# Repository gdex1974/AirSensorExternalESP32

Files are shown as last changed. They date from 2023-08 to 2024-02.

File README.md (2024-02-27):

# Air Quality Sensor - external unit

## Description

The Air Quality Sensor project contains two parts:
- [Internal unit](https://github.com/gdex1974/AirSensorInternalESP32) - the main unit placed inside the building
- External unit - the unit placed outside the building
This repository contains the hardware and software definitions for the external unit.
In the current state it's based on ESP32C3 module from DFRobot and communicate with the internal unit by ESP-NOW protocol.
The temperature, humdity and pressure are measured each minute. The PMx values are measured each hour.

## Hardware

- [Beetle ESP32-C3](https://wiki.dfrobot.com/SKU_DFR0868_Beetle_ESP32_C3) main microcontroller board
- [SPS30](https://botland.store/air-quality-sensors/15062-dust-air-sensor-sps30-pm10-pm25-pm4--5904422366094.html) sensor for particles matter measurement
- [BME280](https://botland.store/pressure-sensors/11803-bme280-humidity-temperature-and-pressure-5904422366179.html) sensor for temperature, humidity and pressure measurement
- [Pololu Mini MOSFET Switch](https://www.pololu.com/product/2810) low voltage module switch
- [Pololu U1V10F5](https://www.pololu.com/product/2564) 5V step-up module
- [Module with microUSB socket](https://botland.store/protoboard-connector-board-accessories/7668-module-with-microusb-socket-5904422300678.html) 5V power module
- [Li-Pol Akyga 1950mAh 1S 3,7V](https://www.akyga.com/products/344-lithium-polymer-battery-3-7v-1950mah-pcm-wires-l-150mm.html) Li-Pol accumulator
- [Prototype board](https://botland.store/circuit-boards/2715-universal-double-sided-board-30x70mm-5904422303280.html) used to fit most of the components

Alternalively, the ESP32-based compact boards like Lolin32-Lite could be used, the possible parts and schematics are described [here](docs/Lolin32-lite/Schematics.md)
## Software

- [esp-idf](https://github.com/espressif/esp-idf/releases/tag/v4.4.5) main framework
- [general-support-library](https://github.com/gdex1974/embedded-general-support-library) common embedded library
- [SimpleDrivers](https://github.com/gdex1974/embedded-simple-drivers) simple embedded drivers for SPS30 and BME280 sensors

## Setup

The microcontroller, switch, step-up converter and BME-280 sensor are placed on the prototype board.
It has to be cut to fit the size of the external cover. The SPS30 sensor and micro-USB socket module are placed aside and connected to the main board by the wires.
The frame and cover parts are 3D printed.

### Connection schema:

[Beetle C3 based schema](docs/BeetleC3/Schematics.md)

[Lolin32-lite based schema](docs/Lolin32-lite/Schematics.md)

## Firmware

The firmware is based on ESP-IDF framework (tested version is 4.4.6) and is written in C++17 language. The main task is to read the data from sensors and send them to the internal unit via Esp-Now protocol. The firmware is divided into several modules:

- components - contains the code of the external unit
  - general-support library - contains the code for general support functions, obtained from this repository.
  - SimpleDrivers - contains the code for the SPS30 and BME280 drivers, obtained from this repository.
- main - contains the main code of the external unit's firmware
  - AppConfig - contains the code for the application's configuration
  - AppMain - contains the app_main() function and hosts the controller object.
  - EspNowTransport - contains the code for the communication with the main unit based on Esp-Now protocol
  - DustMonitorController - contains the code for the controller class handling the main logic of the firmware
  - PTHProvider - contains the code for the class providing the data from BME280 sensor
  - SPS30DataProvider - contains the code for the class providing the data from SPS30 sensor
- CMakeLists.txt - main CMake file for the firmware
- sdkconfig - default configuration file for the ESP-IDF framework.

## Build

The main CMakeLists.txt file could be opened directly in IDE.
To build manually, do the following steps:

```shell
mkdir build
cd build
cmake -DIDF_TARGET=esp32c3 -G Ninja  ..
cd ..
idf.py build
```

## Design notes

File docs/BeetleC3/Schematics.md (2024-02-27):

## Schematics

All electronic components except SPS30 and Li-Pol are soldered to the prototype board.
To fit inside the case the board shall be cut from the top right corner to leave 9x12 soldering holes area and one mounting hole.

The Beetle C3 controller is soldered on top close to rear side. BME280 module is soldered vertically using L-shape pins at the front side.
Switch and step-up modules are soldered at the bottom. The connections are made using thin insulated wires.

- SPS30 sensor connection cable:
    - `VCC` is connected to the +5V output of the step-up converter
    - `RX`  is connected to the `IO21` on the Beetle C3
    - `TX`  is connected to the `IO20` on the Beetle C3
    - `SEL` is not connected
    - `GND` is connected to the `GND` on the switch module
- BME280 connection:
    - `SDA` is connected to the `IO1` on the Beetle C3
    - `SCL` is connected to the `IO0` on the Beetle C3
    - `GND` is connected to the `GND` on the switch module
    - `VCC` is connected to the `3V3` output on the Beetle C3
- Pololu 2810 switch connection:
    - `GND` 1 of 4 holes is connected to the GND pin of the C3 board, the others and used as the ground for the other parts
    - `On` is connected to the IO7 pin of the Beetle C3 board
    - `VIN` is connected to the Vbat of the Beetle C3 board
    - `VOUT` one hole is connected to the + input of the step-up converter. The second hole is connected to voltage divider (R1=220k, R2=330k) with the middle point's connected to the `IO4` pad of the Beetle C3.
- step-up converter connection:
    - `Vin` hole is connected to the VBAT pin of the Lolin32-lite board
    - `GND` hole is connected to the GND pin of the Lolin32-lite board
    - `Vout` hole is connected to the VCC pin of the SPS30 sensor.
- microUSB socket connection:
  - 'GND' to the 'GND' pad of the Beetle C3
  - 'VCC' to the 'Vin' pad of the Beetle C3

The stl files:

[PMSensorFrameExternalDFRobot.stl](PMSensorFrameExternalDFRobot.stl) - main frame

[PMSensorCoverExternalDFRobot.stl](PMSensorCoverExternalDFRobot.stl) - external cover

## The assembled device:

The top view on main assembly:
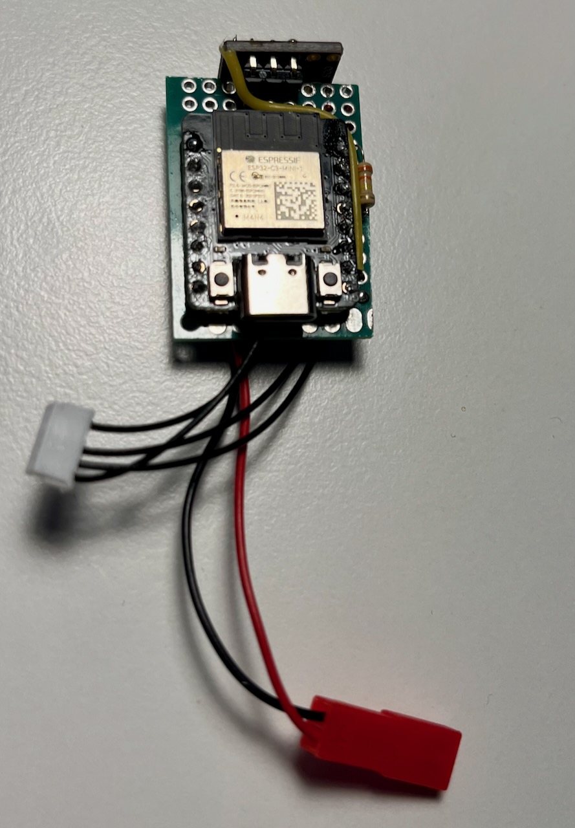
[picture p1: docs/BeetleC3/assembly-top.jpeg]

The bottom view on main assembly:
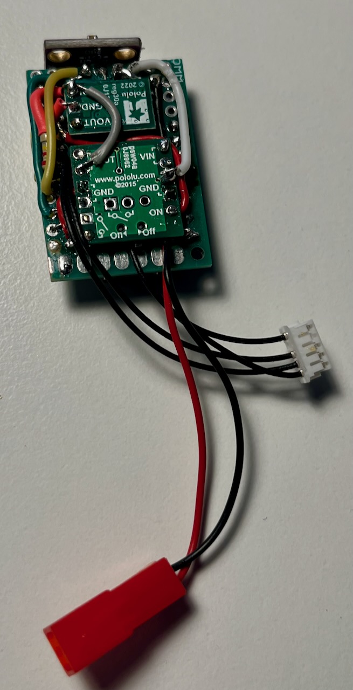
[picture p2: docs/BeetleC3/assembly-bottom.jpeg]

Pre-assembled parts
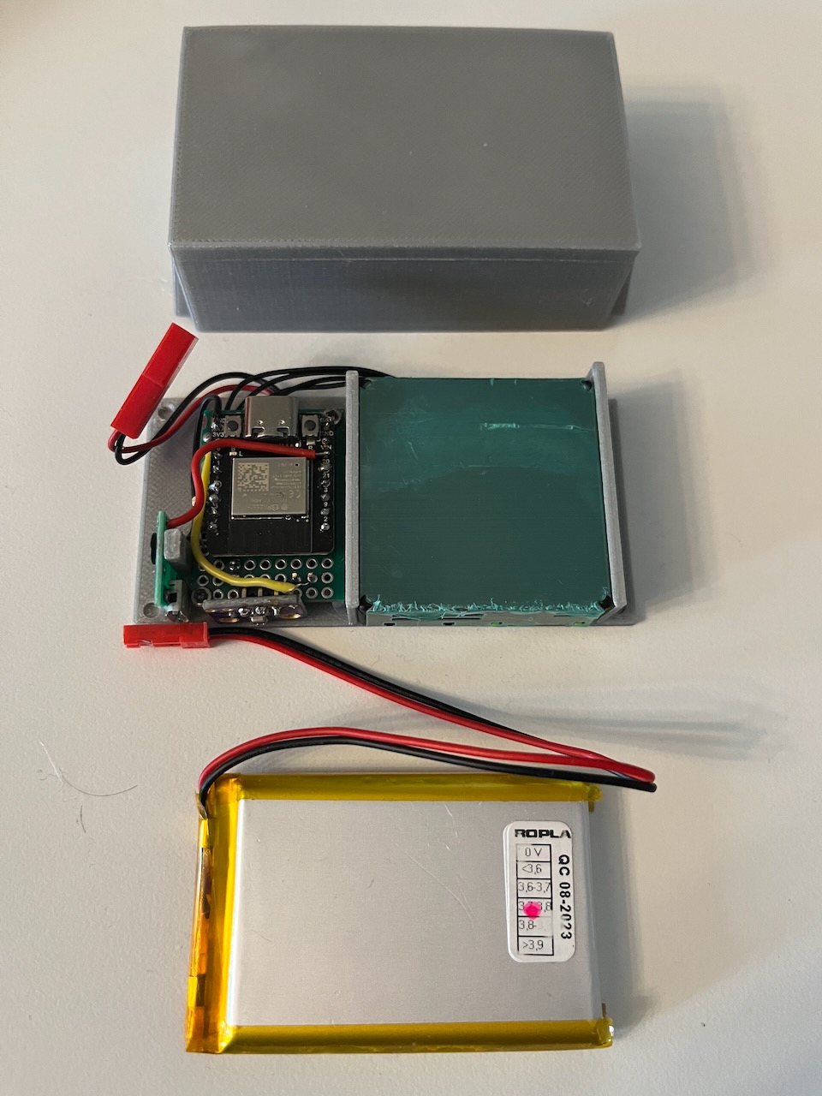
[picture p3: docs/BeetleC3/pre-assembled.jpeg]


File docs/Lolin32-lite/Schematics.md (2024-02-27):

## Schematics

- SPS30 sensor is connected to the UART2 port of the Lolin32-lite board.
    - `VCC` pin of the sensor is connected to the +5V output of the step-up converter
    - `RX` pin of the sensor is connected to the `IO27` pin of the board
    - `TX` pin of the sensor is connected to the `IO26` pin of the board
    - `SEL` pin of the sensor is not connected
    - `GND` pin of the sensor is connected to the `GND` pin of the board
- BME280 module is connected to the I2C port of the Lolin32-lite board
    - `SDA` pin of the sensor is connected to the `IO33` pin of the board
    - `SCL` pin of the sensor is connected to the `IO32` pin of the board
    - `GND` pin of the sensor is connected to the `GND` pin of the board
    - `VCC` pin of the sensor is connected to the `3V3` pin of the board
- Pololu 2810 switch is mounted _under_ the main board and handled by pass-through pins:
    - `GND` connected to the GND pin of the board
    - `Enable` pin connected to the IO12 pin of the Lolin32-lite board (next to the GND pin)
    - `VIN` pin connected to the battery+ of the Lolin32-lite board
    - `VOUT` pin connected to the + input of the step-up converter.  Addtionally, it's connected to voltage divider (R1=220k, R2=330k) and the output of the divider is connected to the `IO2` pin of the board. This pin is used to measure the battery voltage.
- step-up converter's is fixed into separated place on the frame
    - `+` input is connected to the VBAT pin of the Lolin32-lite board
    - `-` input is connected to the GND pin of the Lolin32-lite board
    - `+` output is connected to the VCC pin of the SPS30 sensor.

## Scematics

[external sensor cover](external_sensor_cover.stl)

[external sensor frame](external_sensor_frame.stl)

## The assembled device:

The side view:
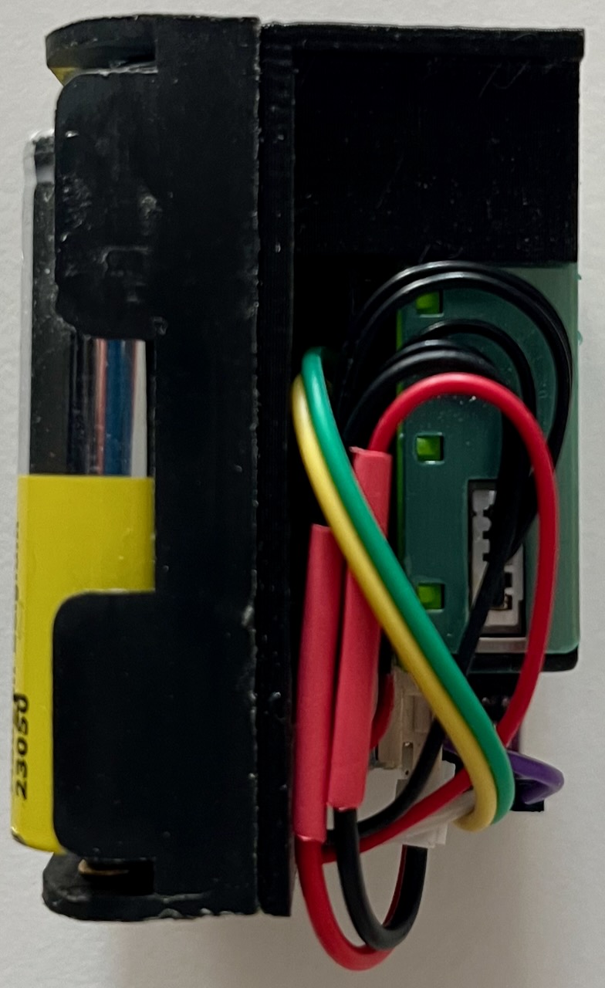
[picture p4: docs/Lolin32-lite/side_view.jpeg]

The top view:
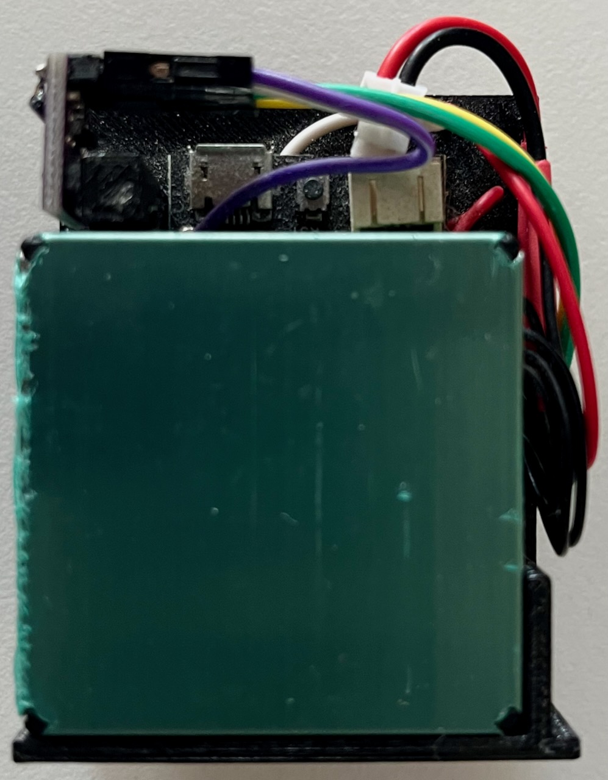
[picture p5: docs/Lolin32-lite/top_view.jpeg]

The connectors' side view:
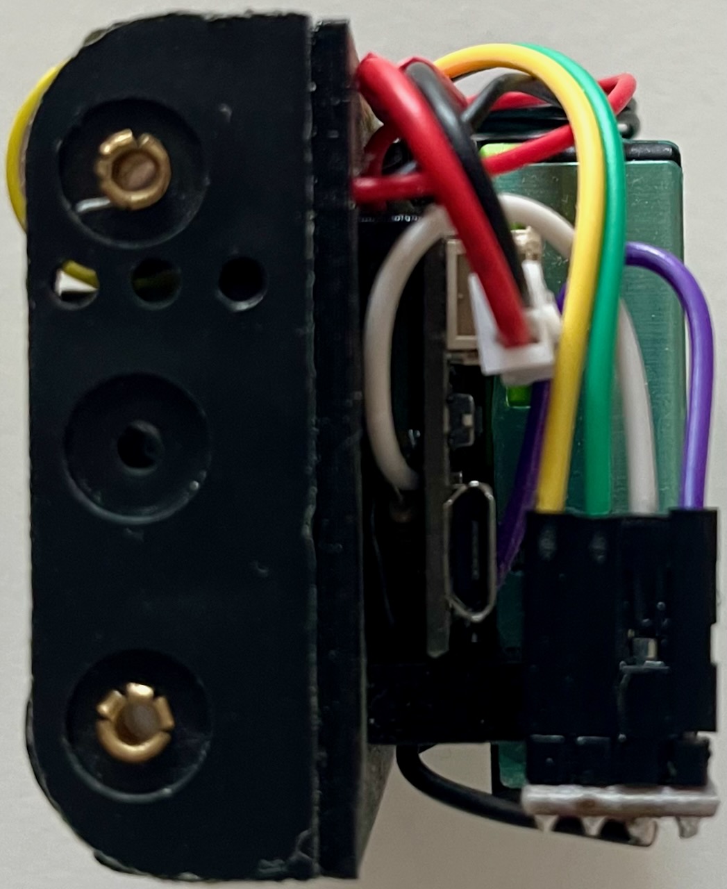
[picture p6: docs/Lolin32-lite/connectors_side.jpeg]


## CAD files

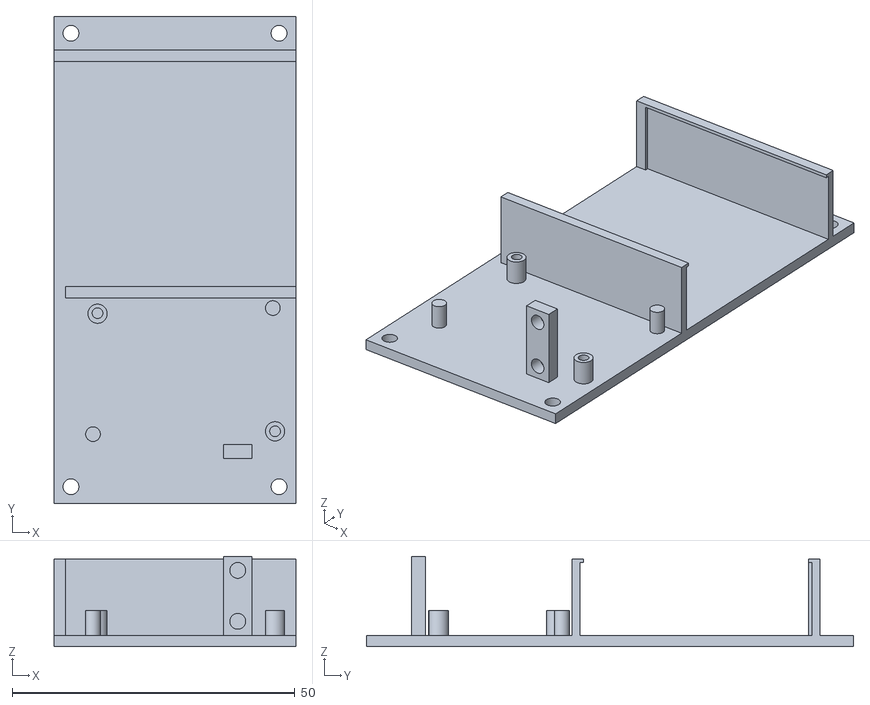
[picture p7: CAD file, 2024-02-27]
docs/BeetleC3/PMSensorFrameExternalDFRobot.stl
42.8 x 86.2 x 16.0

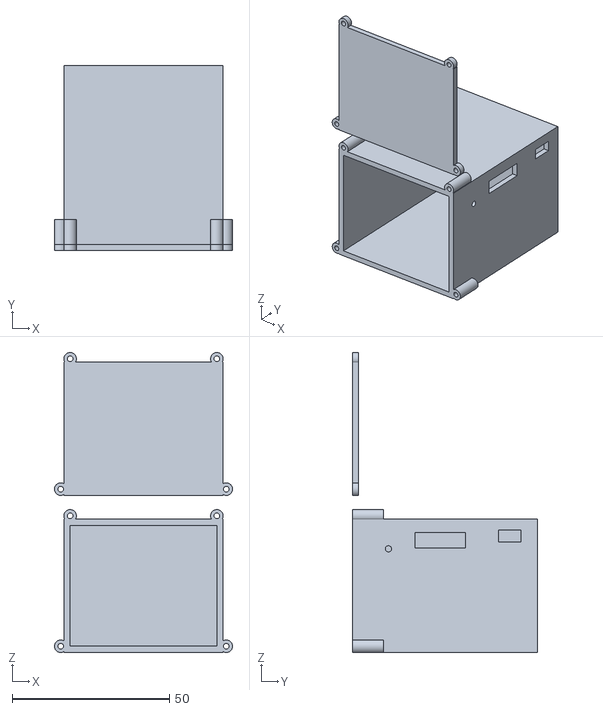
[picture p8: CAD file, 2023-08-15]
docs/Lolin32-lite/external_sensor_cover.stl
56.7 x 59.0 x 95.5

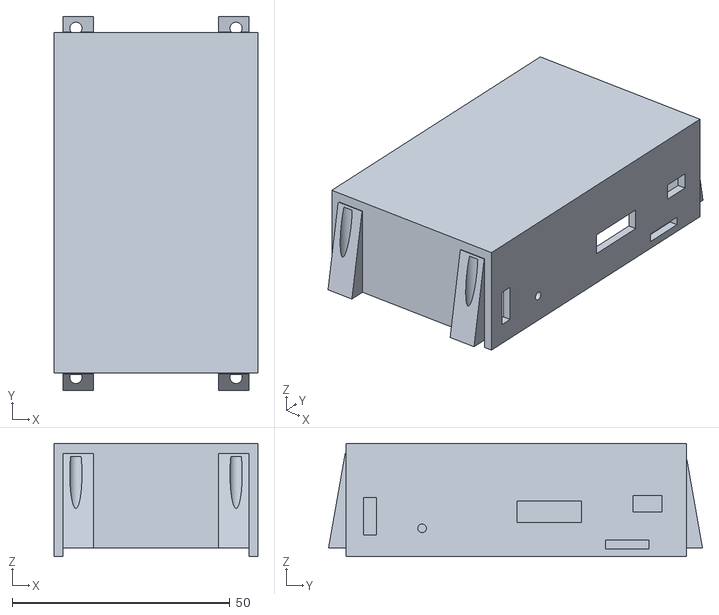
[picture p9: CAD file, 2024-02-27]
docs/BeetleC3/PMSensorCoverExternalDFRobot.stl
46.8 x 85.9 x 26.0

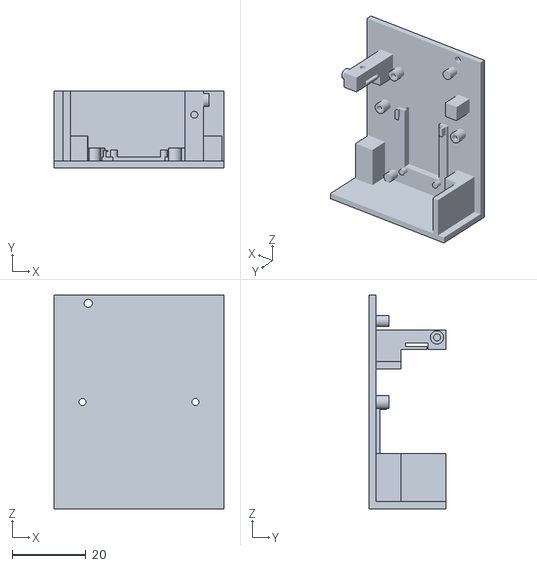
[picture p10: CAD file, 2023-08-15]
docs/Lolin32-lite/external_sensor_frame.stl
46.0 x 21.0 x 58.0

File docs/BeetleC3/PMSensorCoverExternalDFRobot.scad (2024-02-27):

$fn=180;
LiAccHeight=6.5;
LiAccWidth=40;
LiAccLength=60;
module LiIon()
{
    cube([LiAccWidth, LiAccLength, LiAccHeight]);
}

DFRobotC3Width=20.5;
DFRobotC3Length=25.0;
DFRobotC3Shift=1.5;
module DFRobotC3()
{
    height=1;
    width=DFRobotC3Width;
    length=DFRobotC3Length;
    unitWidth=13.2;
    unitLength=16.6;
    unitHeight=2.4;
    usbPlugLength=7.3;
    usbPlugWidth=9;
    cube([length, width, height]);
    translate([-DFRobotC3Shift,(width-usbPlugWidth)/2,height]) cube([usbPlugLength,usbPlugWidth,3]);
    translate([length - unitLength, (width - unitWidth)/2, height]) cube([unitLength, unitWidth, unitHeight]);
}

bmeModuleHeight=11;
module bme280spi()
{
    hole_diameter=2;
    width=15;
    height=bmeModuleHeight;
    cube([1.5, width, height]);
    translate([0, width/2, 3.6]) rotate([0, 90, 0]) cylinder(d=hole_diameter, h=5, center = false);
}

module mainUnit()
{
    boardWidth=24.4;
    boardLength=34.4;
    boardHeight=1.4;
    secondaryBoardsHeight=1.0;
    spacerHeight=2.4;
    switchLength=15.3;
    switchWidth=15.3;
    converterLength=8;
    converterWidth=13.2;
    holeShift=2.2;
    translate([0,0,spacerHeight+secondaryBoardsHeight])
    {
        cube([boardLength, boardWidth, boardHeight]);
        translate([DFRobotC3Shift, 0, boardHeight + spacerHeight]) DFRobotC3();
        translate([boardLength + 1, 2.5, -3.5]) bme280spi();
    }
    translate([4,0,0]) cube([switchLength, switchWidth, secondaryBoardsHeight]);
    translate([4 + switchLength + 2.5,0,0]) cube([converterLength, converterWidth, secondaryBoardsHeight]);
    translate([holeShift, boardWidth-holeShift, -boardHeight/2])cylinder(d=1.9, h=4.4);
    translate([33.6, 1.3, -boardHeight/2])cylinder(d=1.9, h=4.4);
}

sps30Width=41;
sps30Depth=40.8;
sps30Height=12.9;
module sps30()
{
    cube([sps30Depth,sps30Width,sps30Height]);
    bigInletWidth=6.6;
    bigInletHeight=3.8;
    translate([sps30Depth, sps30Width - bigInletWidth - 2.2, 8.2])cube([4,bigInletWidth, bigInletHeight]); // big inlet
    smallInletWidth=10;
    smallInletHeight=2;
    translate([sps30Depth, sps30Width - smallInletWidth - 5.2, -0.2])cube([4,smallInletWidth, smallInletHeight]); // small inlet
    outletWidth=14.8;
    outletHeight=5;
    translate([sps30Depth, 5.5, 5.8])cube([4,outletWidth, outletHeight]); //outlet
}

sps30CableSpace=2;
sps30CaseHeight=sps30Height+0.6;
sps30CaseWalls=2;
sps30Shift=0.6;
module sps30Case()
{
    color("black") translate([0,-sps30CaseWalls,0]) union(){
    translate([0,sps30Shift,0]) cube([sps30Depth, sps30CaseWalls, sps30CaseHeight]);
    translate([-sps30CableSpace,sps30Width+sps30CaseWalls-sps30Shift,0]) cube([sps30Depth+sps30CableSpace, sps30CaseWalls, sps30CaseHeight]);
    }
}

chargePortWidth=5;
frameBaseControlWidth=25.4;
frameBaseThickness=2;
frameBaseWidth=sps30Depth+sps30CableSpace;
frameBaseLength=frameBaseControlWidth + chargePortWidth + sps30Width + 2 * (sps30CaseWalls - sps30Shift);
baseTranslation=- frameBaseLength + sps30Width+ sps30CaseWalls - sps30Shift;
chargePortStallShift=10.3;
chargePortStallHeight=14;
chargePortHolesShift=2.5;
chargePortStallWidth=5;
sideAddition=6;
module mainFrame()
{
    difference()
    {
        sps30Case();
        sps30();
    }
    translate([0, baseTranslation, 0])
    {
        difference()
        {
           union()
           {
               translate([-sps30CableSpace, -sideAddition, - frameBaseThickness])
                    cube([frameBaseWidth, frameBaseLength+2*sideAddition, frameBaseThickness]);

               translate([3.5, chargePortWidth, 0])
               {
                   translate([2.2,22.6,0]) cylinder(d=3.4, h=4.4);
                   translate([33.6,1.8,0]) cylinder(d=3.4, h=4.4);
                   translate([1.4,1.3,0]) cylinder(d=2.6, h=4.4);
                   translate([33.2,23.6,0]) cylinder(d=2.6, h=4.4);
               }
               translate([frameBaseWidth-sps30CableSpace - chargePortStallShift - chargePortStallWidth/2,2,0]) cube([chargePortStallWidth,2.5,chargePortStallHeight]);
                translate([1, -3, -3]) cylinder(d=2.8, h=24);
                translate([frameBaseWidth - 5, -3, -3]) cylinder(d=2.8, h=24);
                translate([1, frameBaseLength + 3, -3]) cylinder(d=2.8, h=24);
                translate([frameBaseWidth - 5, frameBaseLength + 3, -3]) cylinder(d=2.8, h=24);
            }
            translate([3.5, 0.5 + chargePortWidth, 1]) mainUnit();
            translate([frameBaseWidth-sps30CableSpace-chargePortStallShift,6,chargePortHolesShift]) rotate([90,0,0]) cylinder(d=2.8, h=5);
            translate([frameBaseWidth-sps30CableSpace-chargePortStallShift,6,chargePortStallHeight - chargePortHolesShift]) rotate([90,0,0]) cylinder(d=2.8, h=5);

        }
    }
}

internalShellHeight=sps30CaseHeight + LiAccHeight + frameBaseThickness;
{
    difference()
    {
        translate([-2, -2, 0]) union() {
            cube([frameBaseWidth+4,frameBaseLength+4,internalShellHeight+4]);
            translate([2,-4,2])rotate([-10,0,0])cube([7,4,internalShellHeight]);
            translate([frameBaseWidth-5,-4,2])rotate([-10,0,0])cube([7,4,internalShellHeight]);
            translate([2,frameBaseLength+4,0])rotate([10,0,0])cube([7,4,internalShellHeight]);
            translate([frameBaseWidth-5,frameBaseLength+4,0])rotate([10,0,0])cube([7,4,internalShellHeight]);
        }
        
        translate([0,0,0])cube([frameBaseWidth,frameBaseLength,internalShellHeight]);

        translate([2, 0, 2])
        {
            translate([0, -baseTranslation,0]) 
            {
                sps30();
                mainFrame();
            }
            translate([3.5, 0.5 + chargePortWidth, 1]) mainUnit();
            translate([frameBaseWidth-sps30CableSpace - chargePortStallShift - chargePortStallWidth/2 +11,2,3]) cube([chargePortStallWidth,3,8.6]);
        }

    }
}

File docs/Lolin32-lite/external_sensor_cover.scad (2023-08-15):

$fn=180;
innerWidth=46.7;
innerHeight=38.5;
innerLength=58;
thickness=2;

module boltplace(length=10, outer=4, inner=1.8)
{
    difference() {
        cylinder(h=length, d=outer);
        cylinder(h=length, d=inner);
    }
};

union() {
    difference() {
        cube([innerWidth + 2 * thickness, innerLength+thickness-1, innerHeight + 2 * thickness]);
        translate([thickness, 0, thickness]) {
            cube([innerWidth, innerLength, innerHeight]);
            translate([innerWidth, 11.5, innerHeight-7.5]) rotate([0,90,0]) cylinder(h=10, d=2, center=true);
            translate([innerWidth, 20, innerHeight-5-2.3]) cube([10,16,5]);
            translate([innerWidth, 46.5, innerHeight-3.8-1.5]) cube([10,7.2,3.8]);
        }
    }

    translate([-1,0,2]) rotate([-90,0,0]) boltplace();
    translate([innerWidth+2*thickness+1,0,2]) rotate([-90,0,0]) boltplace();
    translate([2,0,innerHeight+5]) rotate([-90,0,0]) boltplace();
    translate([innerWidth+2*thickness-2,0,innerHeight+5]) rotate([-90,0,0]) boltplace();

}

translate([0,0,50])
union() {
    translate([-1,0,2]) rotate([-90,0,0]) boltplace(length=thickness);
    translate([innerWidth+2*thickness+1,0,2]) rotate([-90,0,0]) boltplace(length=thickness);
    translate([2,0,innerHeight+5]) rotate([-90,0,0]) boltplace(length=thickness);
    translate([innerWidth+2*thickness-2,0,innerHeight+5]) rotate([-90,0,0]) boltplace(length=thickness);
    cube([innerWidth+2*thickness, thickness, innerHeight+2*thickness]);
}

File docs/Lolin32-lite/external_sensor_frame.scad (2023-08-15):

$fn=180;
module batteryCase(size, radius)
{
height=size[2];//15;
width=size[1];//46;
length=size[0];//58;
//radius = 6;
x = width-radius;
y = height*2-radius;
z = length;
hole_diameter = 1.9;
difference() {
linear_extrude(height=z)
hull()
{
    // place 4 circles in the corners, with the given radius
    translate([(-x/2)+(radius/2), (-y/2)+(radius/2), 0])
    circle(r=radius);

    translate([(x/2)-(radius/2), (-y/2)+(radius/2), 0])
    circle(r=radius);

    translate([(-x/2)+(radius/2), (y/2)-(radius/2), 0])
    circle(r=radius);

    translate([(x/2)-(radius/2), (y/2)-(radius/2), 0])
    circle(r=radius);
}

translate([-50,0,-10])
cube([100,100,100]);
}
translate([15.3,height/2-5,length/2])rotate([90,0,0])cylinder(h=6,d=hole_diameter, center = true);
translate([-15.3,height/2-5,length/2])rotate([90,0,0])cylinder(h=6,d=hole_diameter, center = true);
}

module lolin32Lite()
{
height=7;
width=25.5;
length=50;
radius = 2;
x = length-radius;
y = width-radius;
z = height;
hole_diameter=1.9;
linear_extrude(height=z)
hull()
{
    // place 4 circles in the corners, with the given radius
    translate([(-x/2)+(radius/2), (-y/2)+(radius/2), 0])
    circle(r=radius);

    translate([(x/2)-(radius/2), (-y/2)+(radius/2), 0])
    circle(r=radius);

    translate([(-x/2)+(radius/2), (y/2)-(radius/2), 0])
    circle(r=radius);

    translate([(x/2)-(radius/2), (y/2)-(radius/2), 0])
    circle(r=radius);
}
translate([-(x/2-1), (y/2 - 1.75),height]) cylinder(d=hole_diameter, h=5, center = false);
translate([(x/2-8.5), -(y/2 -1),height]) cylinder(d=hole_diameter, h=5, center = false);
}

module bme280i2c()
{
    hole_diameter=1.9;
    cube([10.5,13.5,4]);
    translate([8, 11, 4]) cylinder(d=hole_diameter, h=5, center = false);
    translate([(10.5-8)/2, 1, 4])cube([8,2,6]);
}


module sps30()
{
    cube([41.2,41.2,12.8]);
}

module stepup5V()
{
    hole_diameter=1.9;
    union()
    {
        cube([18, 24.3, 1.5]);//3.8
        translate([2,-1,-1.5-1.4+0.6]) cube([14,21.7, 2.3+1.4-0.6]);
    }
}
difference() {
translate([-23,2,15]) rotate([90,0,0]) {
color("green"){
cube([46,58,2]);
translate([0,0,-19])cube([46,2,19]);

translate([2.4,0,-19])cube([6.8,15,19]);
translate([38.7,0,-19])cube([6.8,15,19]);

translate([4.5,38,-12])cube([4.5,5,12]);

translate([13,5.7,-1])    cube([20,24.3,1]);
translate([13+0.4,27,-2.8])    cube([1.2,3,2.5]);
translate([13+18.3,27,-2.8])    cube([1.2,3,2.5]);

translate([-9+23,-13.6,-2]) rotate([0,0,0]) union()
{
    //stepup5V();
    translate([(18-1)-1.2, 24.3-1-1.5, -1]) cylinder(d=1.9, h=3, center = false);
    translate([(0+1)+1.2, 24.3-1-1.5, -1]) cylinder(d=1.9, h=3, center = false);
}

translate([35.5,40,-19])
difference() {
union()
{
    cube([5,8.5,19]);
    translate([5,6.5,2.5])rotate([0,90,0])cylinder(d=3.6,h=3, center= true);
}
translate([-1,4,5])cube([7,1,6]);
translate([-1,2,5])cube([7,2,0.2]);
translate([2.5,6.5,6.5])rotate([90,0,0])cylinder(d=1.9,h=5, center= true);
}
translate([23+15.3,29,-1.75])cylinder(h=3.5,d=3.5, center = true);
translate([23-15.3,29,-1.75])cylinder(h=3.5,d=3.5, center = true);
translate([23-11,29-26.5+2,-1.75])cylinder(h=3.5,d=3.5, center = true);
translate([23+12,29-26.5+2,-1.75])cylinder(h=3.5,d=3, center = true);
translate([23+9.75,29+12+2,-1.75])cylinder(h=3.5,d=3.5, center = true);
translate([23-12,29+20+2,-1.75])cylinder(h=3.5,d=3, center = true);
}
}
translate([-21.75+8,1,71.75-1])rotate([90,0,0])cylinder(d=2.2, h=4, center=true);
translate([-1,12.5,40.5+2]) rotate([90,-90,0]) lolin32Lite();

translate([23,10.5,72.5])rotate([-90,0,90]) bme280i2c();

translate([0,0,15])batteryCase([58, 46, 15], 6);
translate([-18.5,21.5,17])rotate([90,0,0])sps30();

translate([-9,3,45]) rotate([-90,0,0]) difference()
{
    stepup5V();
            translate([(18-1)-1.2, 24.3-1-1.5, -2]) cylinder(d=1.9, h=4, center = false);
        translate([(0+1)+1.2, 24.3-1-1.5, -2]) cylinder(d=1.9, h=4, center = false);
}
}

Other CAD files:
docs/BeetleC3/PMSensorFrameExternalDFRobot.scad

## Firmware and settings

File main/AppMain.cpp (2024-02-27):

#include "DustMonitorController.h"

#include "AppConfig.h"

#include "Delays.h"
#include "PacketUart.h"
#include "PersistentStorage.h"

#include "esp32-esp-idf/PacketUartImpl.h"
#include "esp32-esp-idf/I2CBus.h"
#include "esp32-esp-idf/SleepFunctions.h"

#include <esp_system.h>
#include <nvs_flash.h>

#include "Debug.h"

using ResetReason = DustMonitorController::ResetReason;
namespace
{
class ControllerHolder
{
public:
    ControllerHolder(embedded::PersistentStorage& storage, int serialPortNum, int8_t address, bool restrictTxPower)
        : i2CBus(0)
        , i2CDevice(i2CBus, address)
        , uart2Device(serialPortNum)
        , uart2(uart2Device)
        , controller(storage, uart2, i2CDevice, restrictTxPower)
    {
        i2CBus.init(AppConfig::SDA, AppConfig::SCL, 100000);
    }
    DustMonitorController& getController() { return controller; }
private:
    embedded::I2CBus i2CBus;
    embedded::I2CHelper i2CDevice;
    embedded::PacketUart::UartDevice uart2Device;
    embedded::PacketUart uart2;
    DustMonitorController controller;
};

RTC_DATA_ATTR std::array<uint8_t, 2048> persistentArray;
std::optional<embedded::PersistentStorage> persistentStorage;
std::optional<ControllerHolder> controllerHolder;

ResetReason getResetReason()
{
    ResetReason resetReason;
    switch (esp_reset_reason())
    {
    case ESP_RST_DEEPSLEEP:
        resetReason = ResetReason::DeepSleep;
        break;
    case ESP_RST_BROWNOUT:
        resetReason = ResetReason::BrownOut;
        break;
    case ESP_RST_POWERON:
    default:
        resetReason = ResetReason::PowerOn;
        break;
    }
    return resetReason;
}

bool setup(ResetReason resetReason)
{
#ifdef DEBUG_SERIAL_OUT
    embedded::PacketUart::UartDevice::init(0, AppConfig::serial1RxPin, AppConfig::serial1TxPin, 115200);
#endif
    DEBUG_LOG((resetReason == ResetReason::DeepSleep ? "Wake up after sleep" : (resetReason == ResetReason::BrownOut ? "Reset after voltage drop" : "Initial startup")))
    persistentStorage.emplace(persistentArray, resetReason != ResetReason::DeepSleep);
    embedded::PacketUart::UartDevice::init(AppConfig::Sps30UartNum, AppConfig::sps30RxPin, AppConfig::sps30TxPin, 115200);
    controllerHolder.emplace(*persistentStorage, AppConfig::Sps30UartNum, AppConfig::bme280Address, AppConfig::restrictTxPower);
    return controllerHolder->getController().setup(resetReason);
}

}

extern "C" [[noreturn]] void app_main()
{
    esp_err_t ret = nvs_flash_init();
    if (ret == ESP_ERR_NVS_NO_FREE_PAGES || ret == ESP_ERR_NVS_NEW_VERSION_FOUND) {
        ESP_ERROR_CHECK( nvs_flash_erase() );
        ret = nvs_flash_init();
    }
    ESP_ERROR_CHECK( ret );
    ResetReason resetReason = getResetReason();
    if (!setup(resetReason))
    {
        DEBUG_LOG("Setup failed. No sensors found of failed to initialize WiFi. Terminating...")
        embedded::delay(1000);
        std::terminate();
    }

    const auto delayTime = controllerHolder->getController().process();
    controllerHolder->getController().hibernate();
    DEBUG_LOG("Going to deep sleep for " << delayTime << " ms")
    embedded::deepSleep(delayTime);
}

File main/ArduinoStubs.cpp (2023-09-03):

#include "DustMonitorController.h"

#include "AppConfig.h"

#include "Delays.h"
#include "PacketUart.h"
#include "PersistentStorage.h"

#include "esp32-esp-idf/PacketUartImpl.h"
#include "esp32-esp-idf/I2CBus.h"
#include "esp32-esp-idf/SleepFunctions.h"

#include <esp_system.h>
#include <nvs_flash.h>

#include "Debug.h"

namespace
{
struct DriversHolder
{
    DriversHolder(embedded::PersistentStorage& storage, int i2CBusNum, int serialPortNum, int8_t address)
        : i2CBus(i2CBusNum)
        , i2CDevice(i2CBus, address)
        , uart2Device(serialPortNum)
        , uart2(uart2Device)
        , controller(storage, uart2, i2CDevice)
    {
        i2CBus.init(AppConfig::SDA, AppConfig::SCL, 100000);
    }
    embedded::I2CBus i2CBus;
    embedded::I2CHelper i2CDevice;
    embedded::PacketUart::UartDevice uart2Device;
    embedded::PacketUart uart2;
    DustMonitorController controller;
};

RTC_DATA_ATTR std::array<uint8_t, 2048> persistentArray;
std::optional<embedded::PersistentStorage> persistentStorage;
std::optional<DriversHolder> driversHolder;

bool wakeUp = false;
}

void setup()
{
    wakeUp = esp_reset_reason() == ESP_RST_DEEPSLEEP;
    persistentStorage.emplace(persistentArray, !wakeUp);
#ifdef DEBUG_SERIAL_OUT
    embedded::PacketUart::UartDevice::init(0, AppConfig::serial1RxPin, AppConfig::serial1TxPin, 115200);
#endif
    DEBUG_LOG((wakeUp ? "Wake up after sleep" : "Initial startup"))
    embedded::PacketUart::UartDevice::init(2, AppConfig::serial2RxPin, AppConfig::serial2TxPin, 115200);
    driversHolder.emplace(*persistentStorage, 0, 2, AppConfig::bme280Address);
    if (!driversHolder->controller.setup(wakeUp)) {
        DEBUG_LOG("Setup failed!");
    }
}

void loop()
{
    auto delayTime = driversHolder->controller.process();
    if (delayTime > 700)
    {
        driversHolder->controller.hibernate();
        DEBUG_LOG("Going to deep sleep for " << delayTime << " ms")
        embedded::deepSleep(delayTime);
    }
    embedded::delay(delayTime);
}

extern "C" void app_main()
{
    esp_err_t ret = nvs_flash_init();
    if (ret == ESP_ERR_NVS_NO_FREE_PAGES || ret == ESP_ERR_NVS_NEW_VERSION_FOUND) {
        ESP_ERROR_CHECK( nvs_flash_erase() );
        ret = nvs_flash_init();
    }
    ESP_ERROR_CHECK( ret );
    setup();
    while (true)
    {
        loop();
    }
}

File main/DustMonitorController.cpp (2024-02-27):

#include "DustMonitorController.h"
#include "HardwareSensorControl.h"

#include "TimeFunctions.h"
#include "AppConfig.h"

#include <PacketUart.h>
#include <PersistentStorage.h>
#include "AnalogPin.h"

#include "esp32-esp-idf/GpioPinDefinition.h"

#include <Debug.h>

namespace
{
constexpr int sps30MeasurementDuration = 30; //seconds
constexpr int insufficientPowerThreshold = 50 * 60; //seconds

constexpr float rawToVolts = 3.3f/4095;
constexpr std::string_view controllerDataTag = "DMC";

bool isTimeSyncronized(time_t time)
{
    return time > 1692025000;
}

tm getLocalTime(time_t time)
{
    tm info {};
    localtime_r(&time, &info);
    return info;
}

int readVoltageRaw()
{
    embedded::GpioPinDefinition voltagePin { AppConfig::voltagePin };
    const auto voltage = embedded::AnalogPin(voltagePin).singleRead();
    DEBUG_LOG("VoltageRaw is " << voltage)
    return voltage;
}

void correctTime(const int64_t correction)
{
    if (std::abs(correction) > 10000)
    {
        auto nowMicroseconds = microsecondsNow();
        nowMicroseconds += correction;
        const auto nowSeconds = static_cast<decltype(timeval::tv_sec)>(nowMicroseconds / microsecondsInSecond);
        timeval correctedTimeval {
                .tv_sec = nowSeconds,
                .tv_usec = static_cast<decltype(timeval::tv_usec)>(nowMicroseconds - nowSeconds * microsecondsInSecond)
        };
        settimeofday(&correctedTimeval, nullptr);
        DEBUG_LOG("Time is corrected by " << correction << " us")
    }
    else
    {
        DEBUG_LOG("Small correction factor " << correction << " us is skipped")
    }
}

enum class SensorFlags : uint32_t {
    BatteryFailure = 1 << 0,
};
} // namespace

bool DustMonitorController::setup(ResetReason resetReason)
{
    bool wakeUp = resetReason == ResetReason::DeepSleep;
    if (!wakeUp)
    {
        HardwareSensorControl::initStepUpControl(false);
        controllerData.insufficientPower = (resetReason == ResetReason::BrownOut);
        HardwareSensorControl::activateDeepSleepGpioHold();
        HardwareSensorControl::switchStepUpConversion(true);
    }
    else
    {
        if (auto data = storage.get<ControllerData>(controllerDataTag))
        {
            controllerData = *data;
        }
        HardwareSensorControl::initStepUpControl(SPS30Status::Measuring == controllerData.sps30Status);
    }
    sensorPresent = dustData.setup(wakeUp);
    if (!wakeUp)
    {
        controllerData.voltageRaw = readVoltageRaw();
        if (sensorPresent)
        {
            const auto serial = dustData.getSpsSerial();
            memcpy(controllerData.sps30Serial, serial.begin(), serial.size());
            dustData.sleep();
            HardwareSensorControl::switchStepUpConversion(false);
        }
    }
    auto meteoResul = meteoData.setup(wakeUp);
    auto viewResult = transport.setup(controllerData.sps30Serial, wakeUp);
    return (meteoResul | sensorPresent)  && viewResult ;
}

uint32_t DustMonitorController::process()
{
    const auto currentTime = time(nullptr);
    const bool isTimeGood = isTimeSyncronized(currentTime);
    if (isTimeGood)
    {
        if (controllerData.firstSyncTime == 0)
        {
            controllerData.firstSyncTime = currentTime;
        }
        if (sensorPresent)
        {
            if (!controllerData.insufficientPower)
            {
                processSPS30Measurement();
            }
            else
            {
                HardwareSensorControl::switchStepUpConversion(false);
                if (currentTime - controllerData.firstSyncTime > insufficientPowerThreshold)
                {
                    controllerData.insufficientPower = false;
                }
            }
        }
        needSend = getLocalTime(currentTime).tm_sec == 59;
    }
    else
    {
        needSend = true;
    }

    if (needSend)
    {
        needSend = false;
        if (meteoData.activate() && meteoData.doMeasure())
        {
            meteoData.hibernate();
        }
        transport.sendData(
                { meteoData.getHumidity(), meteoData.getTemperature(), meteoData.getPressure(), controllerData.pm01
                  , controllerData.pm25, controllerData.pm10, float(controllerData.voltageRaw) * rawToVolts / AppConfig::batteryVoltageDivider
                  , (controllerData.insufficientPower ? (uint32_t)SensorFlags::BatteryFailure : 0) });
    }
    if (transport.getStatus() == EspNowTransport::SendStatus::Completed)
    {
        correctTime(transport.getCorrection());
    }

    auto nowMicroseconds = microsecondsNow();
    const int64_t wholeMinutePast = (nowMicroseconds / microsecondsInMinute) * microsecondsInMinute;
    const auto microsecondsTillNextMinute = wholeMinutePast + microsecondsInMinute - nowMicroseconds;
    uint32_t delayTime = (microsecondsTillNextMinute <= HardwareSensorControl::bootEstimationMicroseconds) ?
                        microsecondsInMinute + microsecondsTillNextMinute : microsecondsTillNextMinute;
    delayTime -= HardwareSensorControl::bootEstimationMicroseconds;

    if (controllerData.sps30Status == SPS30Status::Measuring)
    {
        delayTime = std::min(delayTime, uint32_t(sps30MeasurementDuration * microsecondsInSecond));
    }
    return static_cast<uint32_t>(delayTime/1000);
}
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

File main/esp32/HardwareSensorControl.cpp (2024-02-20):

#include "../HardwareSensorControl.h"

#include "AppConfig.h"
#include "Delays.h"

#include <hal/gpio_types.h>
#include <driver/rtc_io.h>

const int HardwareSensorControl::bootEstimationMicroseconds = 700000;

void HardwareSensorControl::initStepUpControl(bool set)
{
    (void)set;// this is not necessary for ESP32
    const auto stepUpPin = (gpio_num_t)AppConfig::stepUpPin;
    rtc_gpio_init(stepUpPin); //initialize the RTC GPIO port
    rtc_gpio_set_direction(stepUpPin, RTC_GPIO_MODE_OUTPUT_ONLY); //set the port to output only mode
    rtc_gpio_hold_dis(stepUpPin); //disable hold before setting the level
}

void HardwareSensorControl::switchStepUpConversion(bool enable)
{
    const auto stepUpPin = (gpio_num_t)AppConfig::stepUpPin;
    rtc_gpio_set_level(stepUpPin, enable? 1 : 0);
    if (enable)
    {
        embedded::delay(20);
    }
}

void HardwareSensorControl::holdStepUpConversion()
{
    const auto stepUpPin = (gpio_num_t)AppConfig::stepUpPin;
    rtc_gpio_hold_en(stepUpPin);
}

void HardwareSensorControl::activateDeepSleepGpioHold()
{
}

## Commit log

2023-08-15 Add documentation for the project
    [external_sensor_cover.scad, external_sensor_cover.stl, external_sensor_frame.scad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]
2023-08-26 Make version without Arduino dependency main. (#10)
    * Adjust PTHProvider to new BME280 interface.
    * Pull general-support-library
    * Fix time correction
    * Remove Arduino SDK.
    * Update README.md
    ---------
    [ArduinoStubs.cpp, DustMonitorController.cpp]
2023-09-03 Merge changes from master to main (#11)
    * Add photos of the unit to docs.
    * Use persistent storage in data providers and transport
    Fix sleep interval without connection to internal unit.
    * Fix submodules
    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
    [ArduinoStubs.cpp, DustMonitorController.cpp]
2024-02-11 Merge changes from master to main (#14)
    * Do PM measurement only after time synchronisation.
    * Add build stage for the pipeline.
    * Update .gitlab-ci.yml file
    * Update .gitlab-ci.yml file
    * Set secret detection config
    * Do PM measurement only after time synchronisation.
    * Extended error handling
    * Ad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
    [AppMain.cpp, DustMonitorController.cpp]
2024-02-11 Pull recent changes from internal gitlab. (#13)
    * Extended error handling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
2024-02-20 Merge latest remote master to main (#15)
    * A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
    [DustMonitorController.cpp, HardwareSensorControl.cpp]
2024-02-27 Merge external changes from master to main (#16)
    * Extended error handlin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
    [PMSensorCoverExternalDFRobot.scad, PMSensorCoverExternalDFRobot.stl, PMSensorFrameExternalDFRobot.scad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]
2024-03-18 Merge master to main (#17)
    * Add UART number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
2024-11-14 Merge changes from master branch to main (#18)
    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
